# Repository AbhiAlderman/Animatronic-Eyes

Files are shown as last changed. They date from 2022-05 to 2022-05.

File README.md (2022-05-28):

# Animatronic-Eyes
Pair of 3D-printed animatronic eyes equipped with an ESP32-CAM microcontroller. Capable of livestreaming video feed to web server and detecting faces. Uses the position of the face to make the 3D printed eyes "follow" the face.

The main code can be found under Animatronic-Eyes/eyeanimatronic-main/software/accessPointWebServer/accessPointWebServer.ino.

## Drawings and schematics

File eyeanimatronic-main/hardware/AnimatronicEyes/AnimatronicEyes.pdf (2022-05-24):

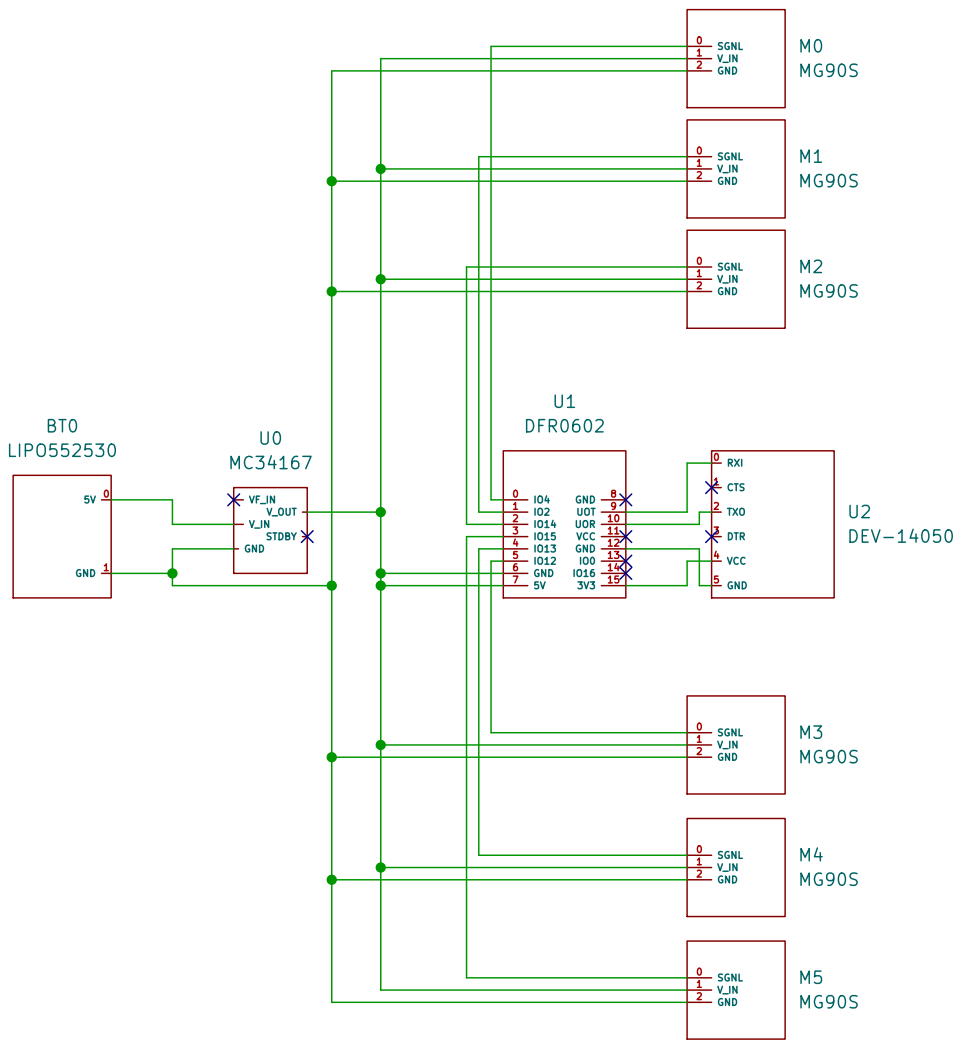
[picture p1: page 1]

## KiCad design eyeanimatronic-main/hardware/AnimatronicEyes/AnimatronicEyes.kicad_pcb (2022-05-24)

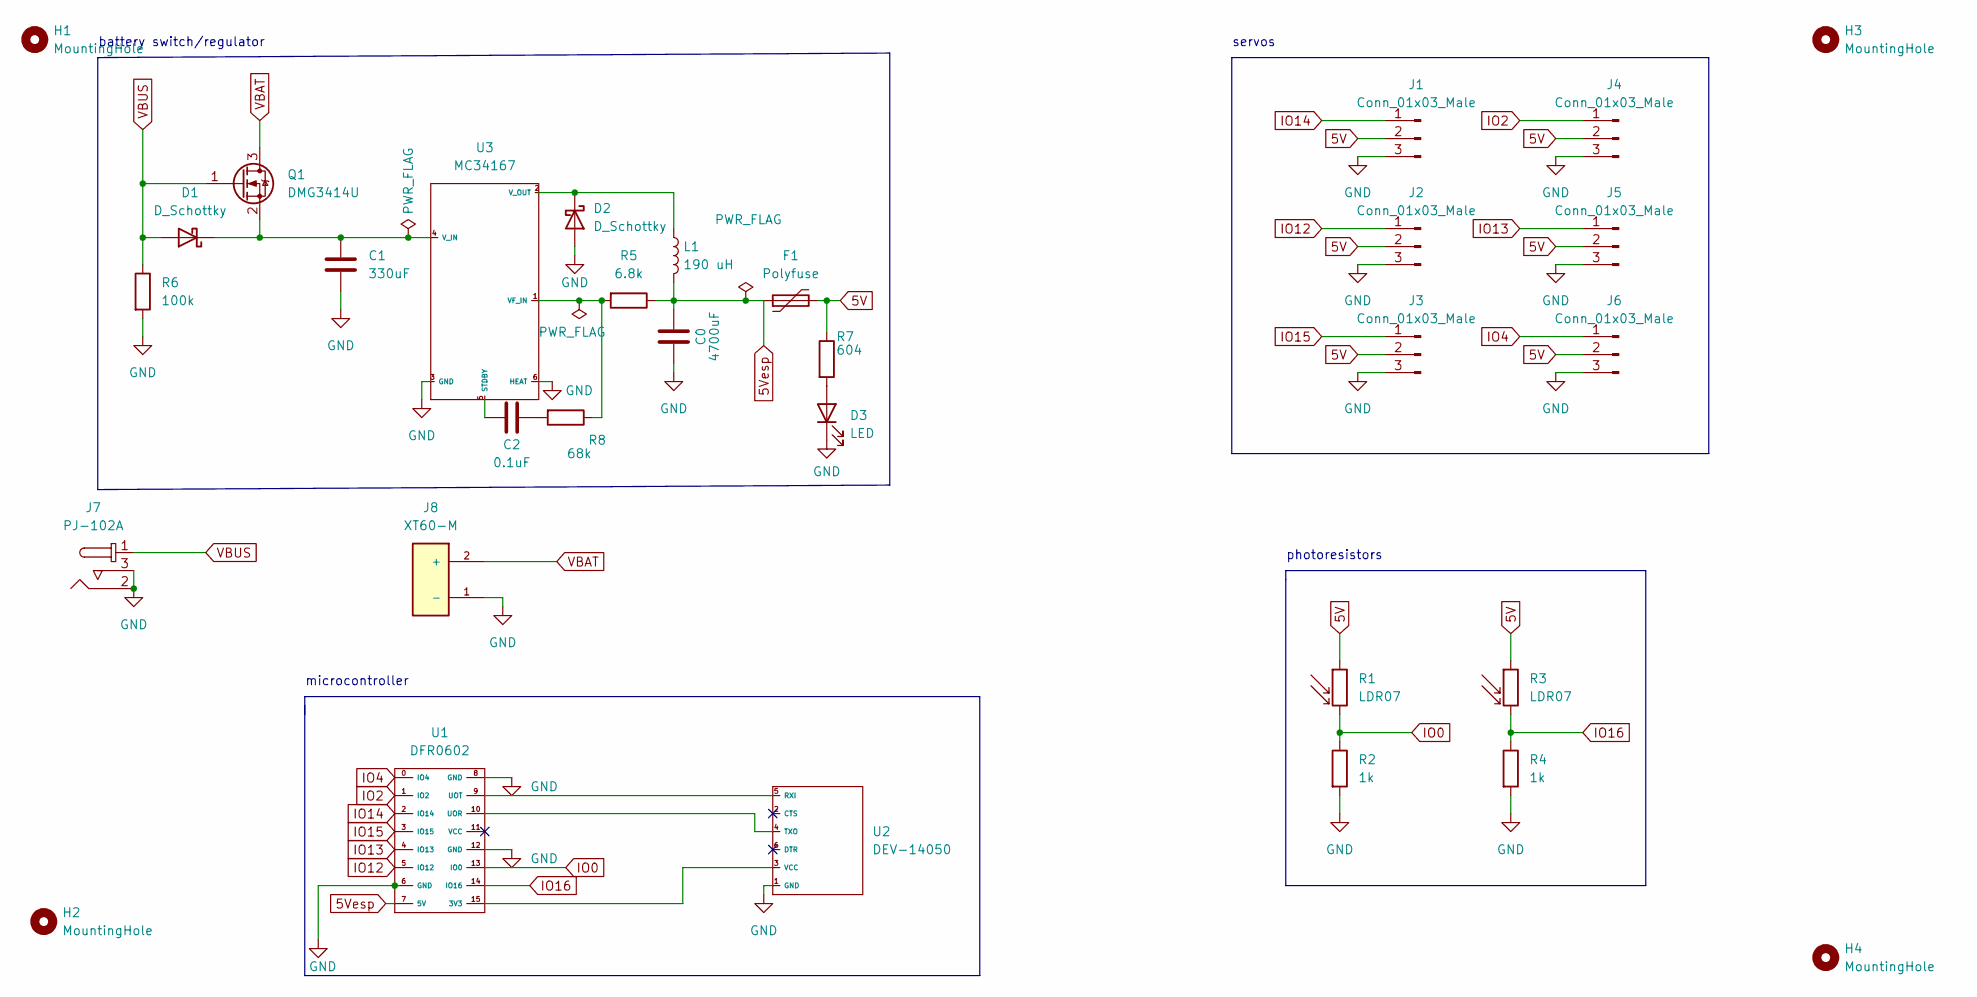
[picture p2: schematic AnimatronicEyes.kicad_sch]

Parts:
C0: 4700uF; CP_Radial_D16.0mm_P7.50mm
C1: 330uF; CP_Radial_D10.0mm_P5.00mm
C2: 0.1uF; C_0603_1608Metric
D1, D2: D_Schottky; D_SMA
D3: LED; LED_0603_1608Metric
F1: Polyfuse; Fuse_0805_2012Metric
H1, H2, H3, H4: MountingHole; MountingHole_2.1mm
J1, J2, J3, J4, J5, J6: Conn_01x03_Male; FanPinHeader_1x03_P2.54mm_Vertical
J7: PJ-102A; barreljack-eye; MPN PJ-102A; Digi-Key_PN CP-102A-ND
J8: XT60-M; PARTREV 1.2
L1: 190 uH; SRR1280-181K
Q1: DMG3414U; SOT-23
R1, R3: LDR07; R_LDR_5.1x4.3mm_P3.4mm_Vertical
R2, R4: 1k; R_0603_1608Metric
R5: 6.8k; R_0603_1608Metric
R6: 100k; R_0603_1608Metric
R7: 604; R_0603_1608Metric
R8: 68k; R_0603_1608Metric
U1: DFR0602; ESP32-Cam
U2: DEV-14050; PinHeader_1x06_P2.54mm_Vertical
U3: MC34167; MC34167 - 5V StepDownRegulator

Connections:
5V: F1.2, J1.2, J2.2, J3.2, J4.2, J5.2, J6.2, R1.1, R3.1, R7.1
5Vesp: C0.2, F1.1, L1.2, R5.1, U1.7 (5V)
GND: C0.1, C1.2, D2.2 (A), D3.1 (K), J1.3, J2.3, J3.3, J4.3, J5.3, J6.3, J7.2, J7.3, J8.1 (-), R2.2, R4.2, R6.2, U1.6 (GND), U1.8 (GND), U1.12 (GND), U2.1 (GND), U3.3 (GND), U3.6 (HEAT)
IO0: R1.2, R2.1, U1.13 (IO0)
IO2: J4.1, U1.1 (IO2)
IO4: J6.1, U1.0 (IO4)
IO12: J2.1, U1.5 (IO12)
IO13: J5.1, U1.4 (IO13)
IO14: J1.1, U1.2 (IO14)
IO15: J3.1, U1.3 (IO15)
IO16: R3.2, R4.1, U1.14 (IO16)
unnamed: C1.1, D1.1 (K), Q1.2 (S), U3.4 (V_IN)
unnamed: C2.1, U3.5 (STDBY)
unnamed: C2.2, R8.2
unnamed: D2.1 (K), L1.1, U3.2 (V_OUT)
unnamed: D3.2 (A), R7.2
unnamed: R5.2, R8.1, U3.1 (VF_IN)
unnamed: U1.9 (UOT), U2.5 (RXI)
unnamed: U1.10 (UOR), U2.4 (TXO)
unnamed: U1.15 (3V3), U2.3 (VCC)
VBAT: J8.2 (+), Q1.3 (D)
VBUS: D1.2 (A), J7.1, Q1.1 (G), R6.1

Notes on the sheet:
servos
microcontroller
battery switch/regulator
photoresistors

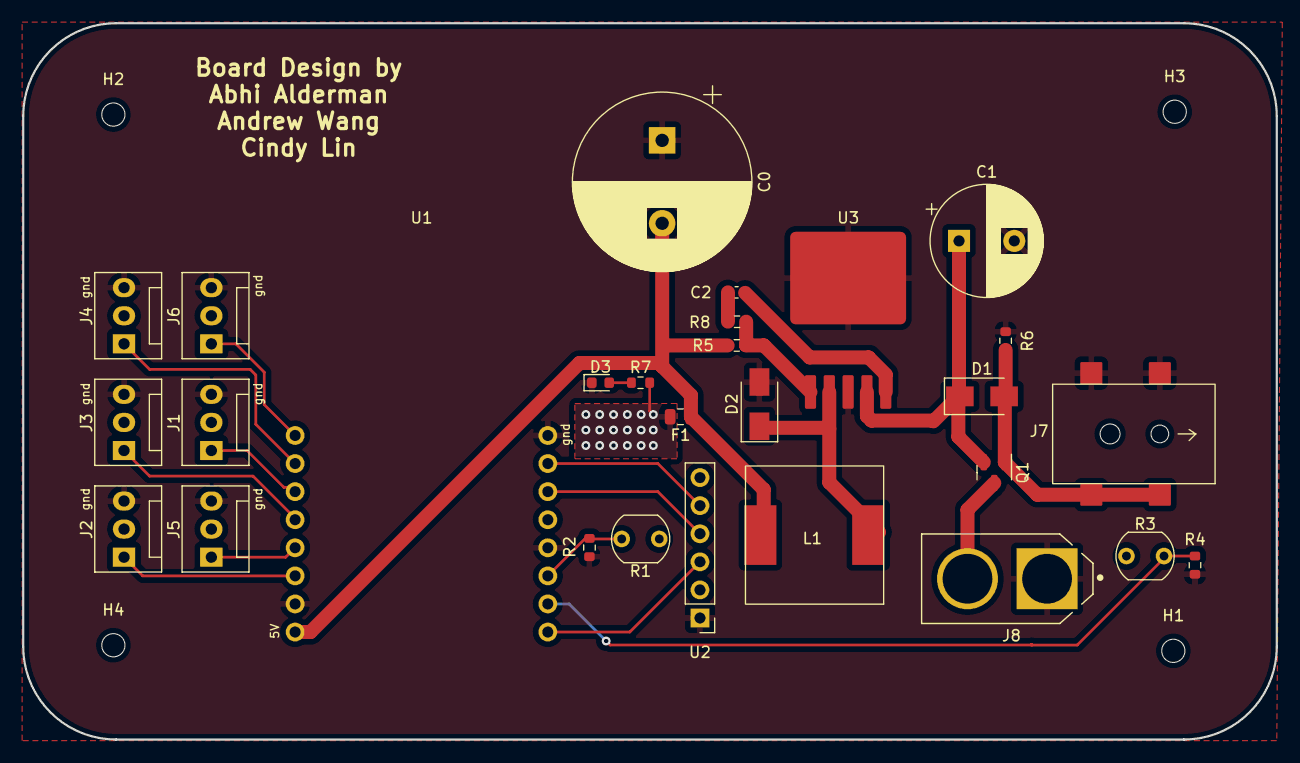
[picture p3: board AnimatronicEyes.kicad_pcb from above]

Board: 2 copper layers, 113.4 x 64.8 mm, 32 parts (0 on the bottom side), 22 nets.

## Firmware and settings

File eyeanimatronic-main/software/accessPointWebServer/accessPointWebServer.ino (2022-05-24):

#include <Servo.h>


#include "esp_camera.h"
#include "fd_forward.h"
#include "fb_gfx.h"
#include <WiFi.h>

//
// WARNING!!! PSRAM IC required for UXGA resolution and high JPEG quality
//            Ensure ESP32 Wrover Module or other board with PSRAM is selected
//            Partial images will be transmitted if image exceeds buffer size
//

// Select camera model
//#define CAMERA_MODEL_WROVER_KIT // Has PSRAM
//#define CAMERA_MODEL_ESP_EYE // Has PSRAM
//#define CAMERA_MODEL_M5STACK_PSRAM // Has PSRAM
//#define CAMERA_MODEL_M5STACK_V2_PSRAM // M5Camera version B Has PSRAM
//#define CAMERA_MODEL_M5STACK_WIDE // Has PSRAM
//#define CAMERA_MODEL_M5STACK_ESP32CAM // No PSRAM
//#define CAMERA_MODEL_M5STACK_UNITCAM // No PSRAM
#define CAMERA_MODEL_AI_THINKER // Has PSRAM
//#define CAMERA_MODEL_TTGO_T_JOURNAL // No PSRAM

#define FACE_COLOR_WHITE 0x00FFFFFF
#define FACE_COLOR_BLACK 0x00000000
#define FACE_COLOR_RED 0x000000FF
#define FACE_COLOR_GREEN 0x0000FF00
#define FACE_COLOR_BLUE 0x00FF0000
#define FACE_COLOR_YELLOW (FACE_COLOR_RED | FACE_COLOR_GREEN)
#define FACE_COLOR_CYAN (FACE_COLOR_BLUE | FACE_COLOR_GREEN)
#define FACE_COLOR_PURPLE (FACE_COLOR_BLUE | FACE_COLOR_RED)

#include "camera_pins.h"

const char* ssid = "ESP32-CAM Access Point";
const char* password = "faceTime";

void startCameraServer();

mtmn_config_t mtmn_config = {0};
int detections = 0;

Servo upperEyelid1;
Servo lowerEyelid2;
Servo rightUD3;
Servo rightLR4;
Servo leftUD5;
Servo leftLR6;
// U Eyelid, L Eylid, Right up/down, Right left/right, Left up/down, Left left/right
Servo servos[6] = {upperEyelid1, lowerEyelid2, rightUD3, rightLR4, leftUD5, leftLR6};
int pins[6] = {2, 4, 12, 13, 14, 15};

// Define initial positions for each servo
int startpos[6] = {140, 60, 85, 87, 85, 100};
int currpos[6] = {140, 60, 85, 87, 85, 100};

// Define bounds of movement
int minBound[6] = {105, 30, 70, 70, 110, 80}; // Down, right, or closed is LOW
int maxBound[6] = {140, 60, 110, 105, 60, 120}; // Up, left, or open is HIGH

void blink(int dt) {
  int uOpen = maxBound[0];
  int lOpen = maxBound[1];
  int uClosed = minBound[0];
  int lClosed = minBound[1];

  int uInt = uOpen - uClosed;
  int lInt = lOpen - lClosed;
  int numsteps = min(uInt, lInt);

  int uStart = uOpen;
  int lStart = lOpen;

  for (int i = 0; i < numsteps; i++) {
    currpos[0] = uStart - (i * uInt) / numsteps;
    servos[0].write(currpos[0]);
    //Serial.println(currpos[0]);
    currpos[1] = lStart - (i * lInt) / numsteps;
    servos[1].write(currpos[1]);
    //Serial.println(currpos[1]);
    delay(5);
  }

  delay(dt);

  for (int i = numsteps; i > 0; i--) {
    currpos[0] = uStart - (i * uInt) / numsteps;
    servos[0].write(currpos[0]);
    //Serial.println(currpos[0]);
    currpos[1] = lStart - (i * lInt) / numsteps;
    servos[1].write(currpos[1]);
    //Serial.println(currpos[1]);
    delay(5);
  }
}

void moveEye(float xPercent, float yPercent) {
  int lLeft = maxBound[5];
  int lRight = minBound[5];
  int rLeft = maxBound[3];
  int rRight = minBound[3];

    int ltargetX = lLeft - int(xPercent*float(lLeft-lRight));
    int rtargetX = rLeft - int(xPercent*float(rLeft-rRight));
//  int ltargetX = lRight + int(xPercent * float(lLeft - lRight));
//  int rtargetX = rRight + int(xPercent * float(rLeft - rRight));

  int lUp = maxBound[4];
  int lDown = minBound[4];
  int rUp = maxBound[2];
  int rDown = minBound[2];

  //  int ltargetY = yPercent*(lUp-lDown)+lDown;
  //  int rtargetY = yPercent*(rUp-rDown)+rDown;
  int ltargetY = lUp - yPercent * (lUp - lDown);
  int rtargetY = rUp + yPercent * (rDown - rUp);


  int leftLRint = ltargetX - currpos[5];
  int rightLRint = rtargetX - currpos[3];
  int xnumsteps = min(abs(leftLRint), abs(rightLRint));
  int lLRstart = currpos[5];
  int rLRstart = currpos[3];

  int leftUDint = ltargetY - currpos[4];
  int rightUDint = rtargetY - currpos[2];
  int ynumsteps = min(abs(leftUDint), abs(rightUDint));
  int lUDstart = currpos[4];
  int rUDstart = currpos[2];

  //Serial.print("LTarget Y: ");
  //Serial.println(ltargetY);
  //Serial.print("RTarget Y: ");
  //Serial.println(rtargetY);

  int numsteps = min(xnumsteps, ynumsteps);

  for (int i = 0; i < numsteps; i++) {
    // Left Eye Left/Right
    currpos[5] = lLRstart + (i * leftLRint) / numsteps;
    servos[5].write(currpos[5]);
    // Serial.print("L Left/Right: ");
    //Serial.println(currpos[5]);
    // Right Eye Left/Right
    currpos[3] = rLRstart + (i * rightLRint) / numsteps;
    servos[3].write(currpos[3]);
    //Serial.print("R Left/Right: ");
    //Serial.println(currpos[3]);
    // Left Eye Up/Down
    currpos[4] = lUDstart + (i * leftUDint) / numsteps;
    servos[4].write(currpos[4]);
    //Serial.print("L Up/Down: ");
    //Serial.println(currpos[4]);
    // Right Eye Up/Down
    currpos[2] = rUDstart + (i * rightUDint) / numsteps;
    servos[2].write(currpos[2]);
    //Serial.print("L Up/Down: ");
    //Serial.println(currpos[2]);
    delay(30);
  }
}


void setup() {
  for (int i = 0; i < 6; i++) {
    servos[i].attach(pins[i], i + 2);
    servos[i].write(startpos[i]);
  }

  Serial.begin(115200);
  Serial.setDebugOutput(true);
  Serial.println();

  camera_config_t config;
  config.ledc_channel = LEDC_CHANNEL_0;
  config.ledc_timer = LEDC_TIMER_0;
  config.pin_d0 = Y2_GPIO_NUM;
  config.pin_d1 = Y3_GPIO_NUM;
  config.pin_d2 = Y4_GPIO_NUM;
  config.pin_d3 = Y5_GPIO_NUM;
  config.pin_d4 = Y6_GPIO_NUM;
  config.pin_d5 = Y7_GPIO_NUM;
  config.pin_d6 = Y8_GPIO_NUM;
  config.pin_d7 = Y9_GPIO_NUM;
  config.pin_xclk = XCLK_GPIO_NUM;
  config.pin_pclk = PCLK_GPIO_NUM;
  config.pin_vsync = VSYNC_GPIO_NUM;
  config.pin_href = HREF_GPIO_NUM;
  config.pin_sscb_sda = SIOD_GPIO_NUM;
  config.pin_sscb_scl = SIOC_GPIO_NUM;
  config.pin_pwdn = PWDN_GPIO_NUM;
  config.pin_reset = RESET_GPIO_NUM;
  config.xclk_freq_hz = 20000000;
  config.pixel_format = PIXFORMAT_JPEG;
  //

  // if PSRAM IC present, init with UXGA resolution and higher JPEG quality
  //                      for larger pre-allocated frame buffer.
  if (psramFound()) {
    config.frame_size = FRAMESIZE_UXGA;
    config.jpeg_quality = 10;
    config.fb_count = 2;
  } else {
    config.frame_size = FRAMESIZE_SVGA;
    config.jpeg_quality = 12;
    config.fb_count = 1;
  }
  //
#if defined(CAMERA_MODEL_ESP_EYE)
  pinMode(13, INPUT_PULLUP);
  pinMode(14, INPUT_PULLUP);
#endif

  // camera init
  esp_err_t err = esp_camera_init(&config);
  if (err != ESP_OK) {
    Serial.printf("Camera init failed with error 0x%x", err);
    return;
  }

  sensor_t * s = esp_camera_sensor_get();
  // initial sensors are flipped vertically and colors are a bit saturated
  if (s->id.PID == OV3660_PID) {
    s->set_vflip(s, 1); // flip it back
    s->set_brightness(s, 1); // up the brightness just a bit
    s->set_saturation(s, -2); // lower the saturation
  }
  // drop down frame size for higher initial frame rate
  s->set_framesize(s, FRAMESIZE_QVGA);

#if defined(CAMERA_MODEL_M5STACK_WIDE) || defined(CAMERA_MODEL_M5STACK_ESP32CAM)
  s->set_vflip(s, 1);
  s->set_hmirror(s, 1);
#endif

  WiFi.softAP(ssid, password);

  startCameraServer();

  Serial.print("Camera Ready! Use 192.168.4.1 to connect");
  //Serial.print(WiFi.localIP());
  //Serial.println("' to connect");
  mtmn_config = mtmn_init_config();
}

void printCoords(int coord_one, int coord_two, int faceID) {
  Serial.print("Face ");
  Serial.print(faceID);
  Serial.print(" found at x: ");
  Serial.print(coord_one);
  Serial.print(" y: ");
  Serial.println(coord_two);
}

static void rgb_print(dl_matrix3du_t *image_matrix, uint32_t color, const char * str) {
  fb_data_t fb;
  fb.width = image_matrix->w;
  fb.height = image_matrix->h;
  fb.data = image_matrix->item;
  fb.bytes_per_pixel = 3;
  fb.format = FB_BGR888;
  fb_gfx_print(&fb, (fb.width - (strlen(str) * 14)) / 2, 10, color, str);
}

double minX = 60; //mess with this value
double minY = 40; //mess with this value
double maxX = 260; //mess with this value
double maxY = 130;//mess with this value

double dividerX = maxX - minX;
double dividerY = maxY - minY;
float percentX, percentY;
void moveEyesToFace(int positionX, int positionY) {
  if (positionX > maxX) {
    positionX = maxX;
  }
  if (positionX < minX) {
    positionX = minX;
  }
  if (positionY > maxY) {
    positionY = maxY;
  }
  if (positionY < minY) {
    positionY = minY;
  }
  percentX = (positionX - minX) / dividerX;
  percentY = (positionY - minY) / dividerY;
  moveEye(percentX, percentY);

}
int x, y, w, h, center_x, center_y;
float timeSinceStart, lastTimeSinceStart;
void loop() {
    // put your main code here, to run repeatedly:
    //test.write(90);
    timeSinceStart = float(esp_timer_get_time()) / 1000000;
    if (timeSinceStart - lastTimeSinceStart > 7) {
      lastTimeSinceStart = timeSinceStart;
      blink(75);
    }
    camera_fb_t * frame;
    frame = esp_camera_fb_get();
    dl_matrix3du_t *image_matrix = dl_matrix3du_alloc(1, frame->width, frame->height, 3);
    fmt2rgb888(frame->buf, frame->len, frame->format, image_matrix->item);
  
    esp_camera_fb_return(frame);
  
    box_array_t *boxes = face_detect(image_matrix, &mtmn_config);
    //boxes[i] gets info for face i, we only wanna do 1 face at a time.
    if (boxes != NULL) {
      x = (int)boxes->box[0].box_p[0];
      y = (int)boxes->box[0].box_p[1];
      w = (int)boxes->box[0].box_p[2] - x + 1;
      h = (int)boxes->box[0].box_p[3] - y + 1;
      center_x = x + w/2;
      center_y = y + h/2;
      moveEyesToFace(center_x, center_y);
      dl_lib_free(boxes->score);
      dl_lib_free(boxes->box);
      dl_lib_free(boxes->landmark);
      dl_lib_free(boxes);
    }
    //printCoords(center_x, center_y, 0);
    printCoords(center_x, center_y, 0);
    moveEyesToFace(center_x, center_y);
    dl_matrix3du_free(image_matrix);
  /*for(int i = 0; i < 6; i++){
    Serial.print(currpos[i]);
    Serial.print(",");
    }
    Serial.print("\n");
  */

//  if (Serial.available()) {
//    int temp = Serial.parseInt();
//    if (temp != 0) {
//      float targetpos = float(temp) / 100;
//      Serial.println(targetpos);
//      moveEye(targetpos, targetpos);
//    }
//  }




}
/*static void draw_face_boxes(dl_matrix3du_t *image_matrix, box_array_t *boxes, int face_id)
  camera_fb_t * frame;
  frame = esp_camera_fb_get();
  dl_matrix3du_t *image_matrix = dl_matrix3du_alloc(1, frame->width, frame->height, 3);
  fmt2rgb888(frame->buf, frame->len, frame->format, image_matrix->item);

  esp_camera_fb_return(frame);

  box_array_t *boxes = face_detect(image_matrix, &mtmn_config);
  //boxes[i] gets info for face i, we only wanna do 1 face at a time.
  if (boxes != NULL) {
    x = (int)boxes->box[0].box_p[0];
    y = (int)boxes->box[0].box_p[1];
    w = (int)boxes->box[0].box_p[2] - x + 1;
    h = (int)boxes->box[0].box_p[3] - y + 1;
    center_x = x + w/2;
    center_y = y + h/2;
    moveEyesToFace(center_x, center_y);
    dl_lib_free(boxes->score);
    dl_lib_free(boxes->box);
    dl_lib_free(boxes->landmark);
    dl_lib_free(boxes);
  }
  //printCoords(center_x, center_y, 0);

  dl_matrix3du_free(image_matrix);
  }
*/

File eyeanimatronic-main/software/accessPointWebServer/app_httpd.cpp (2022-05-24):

// Copyright 2015-2016 Espressif Systems (Shanghai) PTE LTD
//
// Licensed under the Apache License, Version 2.0 (the "License");
// you may not use this file except in compliance with the License.
// You may obtain a copy of the License at
//
//     http://www.apache.org/licenses/LICENSE-2.0
//
// Unless required by applicable law or agreed to in writing, software
// distributed under the License is distributed on an "AS IS" BASIS,
// WITHOUT WARRANTIES OR CONDITIONS OF ANY KIND, either express or implied.
// See the License for the specific language governing permissions and
// limitations under the License.
#include "esp_http_server.h"
#include "esp_timer.h"
#include "esp_camera.h"
#include "img_converters.h"
#include "fb_gfx.h"
#include "driver/ledc.h"
//#include "camera_index.h"
#include "sdkconfig.h"
#include "camera_index.h"

#if defined(ARDUINO_ARCH_ESP32) && defined(CONFIG_ARDUHAL_ESP_LOG)
#include "esp32-hal-log.h"
#define TAG ""
#else
#include "esp_log.h"
static const char *TAG = "camera_httpd";
#endif

#if CONFIG_ESP_FACE_DETECT_ENABLED

#include "fd_forward.h"

#if CONFIG_ESP_FACE_RECOGNITION_ENABLED
#include "fr_forward.h"

#define ENROLL_CONFIRM_TIMES 5
#define FACE_ID_SAVE_NUMBER 7
#endif

#define FACE_COLOR_WHITE 0x00FFFFFF
#define FACE_COLOR_BLACK 0x00000000
#define FACE_COLOR_RED 0x000000FF
#define FACE_COLOR_GREEN 0x0000FF00
#define FACE_COLOR_BLUE 0x00FF0000
#define FACE_COLOR_YELLOW (FACE_COLOR_RED | FACE_COLOR_GREEN)
#define FACE_COLOR_CYAN (FACE_COLOR_BLUE | FACE_COLOR_GREEN)
#define FACE_COLOR_PURPLE (FACE_COLOR_BLUE | FACE_COLOR_RED)
#endif

#ifdef CONFIG_LED_ILLUMINATOR_ENABLED
int led_duty = 0;
bool isStreaming = false;
#ifdef CONFIG_LED_LEDC_LOW_SPEED_MODE
#define CONFIG_LED_LEDC_SPEED_MODE LEDC_LOW_SPEED_MODE
#else
#define CONFIG_LED_LEDC_SPEED_MODE LEDC_HIGH_SPEED_MODE
#endif
#endif

typedef struct
{
    httpd_req_t *req;
    size_t len;
} jpg_chunking_t;

#define PART_BOUNDARY "123456789000000000000987654321"
static const char *_STREAM_CONTENT_TYPE = "multipart/x-mixed-replace;boundary=" PART_BOUNDARY;
static const char *_STREAM_BOUNDARY = "\r\n--" PART_BOUNDARY "\r\n";
static const char *_STREAM_PART = "Content-Type: image/jpeg\r\nContent-Length: %u\r\nX-Timestamp: %d.%06d\r\n\r\n";

httpd_handle_t stream_httpd = NULL;
httpd_handle_t camera_httpd = NULL;

#if CONFIG_ESP_FACE_DETECT_ENABLED

static int8_t detection_enabled = 0;

static mtmn_config_t mtmn_config = {0};

#if CONFIG_ESP_FACE_RECOGNITION_ENABLED
static int8_t recognition_enabled = 0;
static int8_t is_enrolling = 0;
static face_id_list id_list = {0};
#endif

#endif

typedef struct
{
    size_t size;  //number of values used for filtering
    size_t index; //current value index
    size_t count; //value count
    int sum;
    int *values; //array to be filled with values
} ra_filter_t;

static ra_filter_t ra_filter;

static ra_filter_t *ra_filter_init(ra_filter_t *filter, size_t sample_size)
{
    memset(filter, 0, sizeof(ra_filter_t));

    filter->values = (int *)malloc(sample_size * sizeof(int));
    if (!filter->values)
    {
        return NULL;
    }
    memset(filter->values, 0, sample_size * sizeof(int));

    filter->size = sample_size;
    return filter;
}

static int ra_filter_run(ra_filter_t *filter, int value)
{
    if (!filter->values)
    {
        return value;
    }
    filter->sum -= filter->values[filter->index];
    filter->values[filter->index] = value;
    filter->sum += filter->values[filter->index];
    filter->index++;
    filter->index = filter->index % filter->size;
    if (filter->count < filter->size)
    {
        filter->count++;
    }
    return filter->sum / filter->count;
}

#if CONFIG_ESP_FACE_DETECT_ENABLED
#if CONFIG_ESP_FACE_RECOGNITION_ENABLED
static void rgb_print(dl_matrix3du_t *image_matrix, uint32_t color, const char *str)
{
    fb_data_t fb;
    fb.width = image_matrix->w;
    fb.height = image_matrix->h;
    fb.data = image_matrix->item;
    fb.bytes_per_pixel = 3;
    fb.format = FB_BGR888;
    fb_gfx_print(&fb, (fb.width - (strlen(str) * 14)) / 2, 10, color, str);
}

static int rgb_printf(dl_matrix3du_t *image_matrix, uint32_t color, const char *format, ...)
{
    char loc_buf[64];
    char *temp = loc_buf;
    int len;
    va_list arg;
    va_list copy;
    va_start(arg, format);
    va_copy(copy, arg);
    len = vsnprintf(loc_buf, sizeof(loc_buf), format, arg);
    va_end(copy);
    if (len >= sizeof(loc_buf))
    {
        temp = (char *)malloc(len + 1);
        if (temp == NULL)
        {
            return 0;
        }
    }
    vsnprintf(temp, len + 1, format, arg);
    va_end(arg);
    rgb_print(image_matrix, color, temp);
    if (len > 64)
    {
        free(temp);
    }
    return len;
}
#endif
static void draw_face_boxes(dl_matrix3du_t *image_matrix, box_array_t *boxes, int face_id)
{
    int x, y, w, h, i;
    uint32_t color = FACE_COLOR_YELLOW;
    if (face_id < 0)
    {
        color = FACE_COLOR_RED;
    }
    else if (face_id > 0)
    {
        color = FACE_COLOR_GREEN;
    }
    fb_data_t fb;
    fb.width = image_matrix->w;
    fb.height = image_matrix->h;
    fb.data = image_matrix->item;
    fb.bytes_per_pixel = 3;
    fb.format = FB_BGR888;
    for (i = 0; i < boxes->len; i++)
    {
        // rectangle box
        x = (int)boxes->box[i].box_p[0];
        y = (int)boxes->box[i].box_p[1];
        w = (int)boxes->box[i].box_p[2] - x + 1;
        h = (int)boxes->box[i].box_p[3] - y + 1;
        fb_gfx_drawFastHLine(&fb, x, y, w, color);
        fb_gfx_drawFastHLine(&fb, x, y + h - 1, w, color);
        fb_gfx_drawFastVLine(&fb, x, y, h, color);
        fb_gfx_drawFastVLine(&fb, x + w - 1, y, h, color);
#if 0
        // landmark
        int x0, y0, j;
        for (j = 0; j < 10; j+=2) {
            x0 = (int)boxes->landmark[i].landmark_p[j];
            y0 = (int)boxes->landmark[i].landmark_p[j+1];
            fb_gfx_fillRect(&fb, x0, y0, 3, 3, color);
        }
#endif
    }
}
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
